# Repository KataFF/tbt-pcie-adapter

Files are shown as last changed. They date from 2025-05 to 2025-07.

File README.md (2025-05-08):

# Thunderbolt to PCIe Adapter

Copyright (c) 2022-2024 [Antmicro](https://www.antmicro.com) 
Original design by Antmicro up to rev. 1.0.2.
Further developed by Kajetan Wierszelis (rev. 1.0.3. and later ones)

Render of rev. 1.0.2.

## Overview

This project contains open hardware design files for an adapter board wrapping 4-lane (i.e. 4x) PCIe Gen 3.0 devices into a Thunderbolt 3 uplink.
It is based on the Intel/JHL6340SLLSQ Thunderbolt controller.
The design files were prepared in KiCad 7.x & updated to KiCad 8.x.

## Key features

* Intel JHL6340SLLSQ Thunderbolt 3 controller 
* PCIe x4 expansion slot
* On-board Step-Up DC-DC generating 12V (required by some PCIe cards)

## Project structure

The main directory contains KiCad PCB project files, a LICENSE, and a README.
The remaining files are stored in the following directories:

* `img` - contains graphics for this README
* `doc` - contains schematics in pdf form
* `assets` - contains visual assets for showcasing the board at [Open Hardware Portal](https://openhardware.antmicro.com)

## Licensing

This project is published under the [Apache-2.0](LICENSE) license.

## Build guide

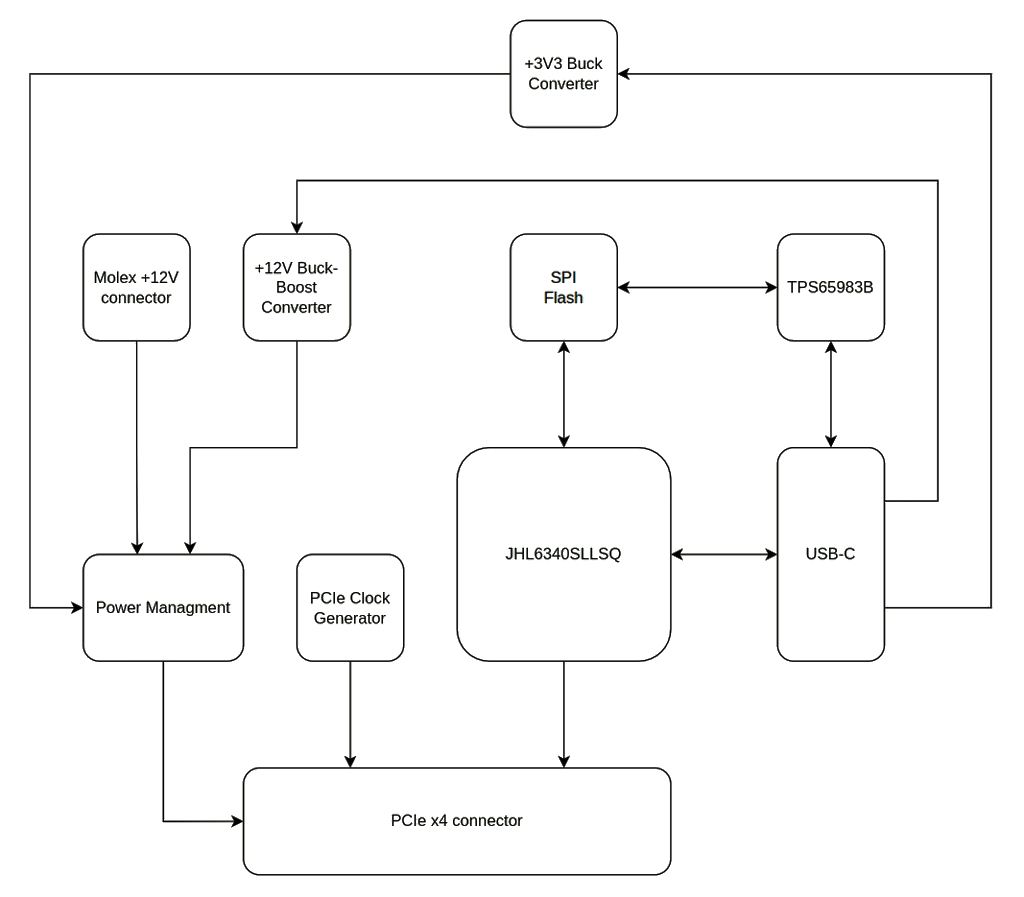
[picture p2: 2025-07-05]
img/thunderbolt-pcie-adapter-diagram-inverted-printable.png

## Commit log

2025-05-08 Update project files to KiCad 8.0.6.
    [connectors.kicad_sch, power.kicad_sch, tb-power.kicad_sch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]
2025-05-09 PCB: N1 board name & rev text: Enlarge to facilitate manufacturabilty, update REV and DATE
2025-05-09 Update revision to 1.0.3.
    [thunderbolt-pcie-adapter.kicad_sch]
2025-05-09 Bring back DRC exclusions from PCB to PROject file
2025-05-21 PCB: Update stackup params to PCBWay 6-layer w/ 1oz outer & 0.5oz inner layers.
    Values were taken from EQ2 as well as the following datasheets:
    https://www.pcbway.com/blog/PCB_Basic_Information/S1000H_Shengyi_Conventional_FR_4_Rigid_PCB_Materials.html
    https://www.chinapcbone.com/images/pdf/S1000H.pdf
    I assumed the original design is based on values for "FR4 Improved" material:
    https://www.eurocircuits.com/downloads/#BaseMaterials
2025-05-22 Update default diff pair width & spacing for USB4&2 to PCBWay stackup external layers
2025-05-22 Lock JHL6340 fanout traces for DP adjustment
2025-07-03 PCB: Generate and add Interactive HTML BOM + project config settings
2025-07-04 SCH: Fix typo in Title Block, clarify authorship
    [connectors.kicad_sch, power.kicad_sch, tb-power.kicad_sch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]
